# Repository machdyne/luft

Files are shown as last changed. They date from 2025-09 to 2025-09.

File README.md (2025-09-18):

# Luft Air Sensor Controller

Luft is an experimental open-source air sensor controller with sockets for up to four MQ gas sensor modules. In addition to MQ modules, you can also connect a SEN55 module (particulate matter, Volatile Organic Compounds, Nitrogen Oxides, humidity, and temperature) and a I2C oxygen sensor, CO₂ sensor, or other I2C sensors.

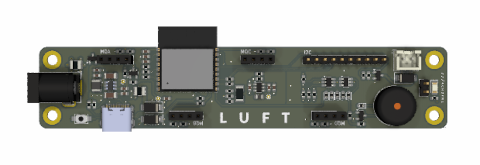
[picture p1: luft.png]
Luft


Luft enables remote monitoring of gasses, air quality and other environmental factors.

The alarm can be triggered by either the MCU or the MQ modules based on their potentiometer setting. The alarm is only activated when JP1 is shunted with a jumper or key switch.

This repo contains schematics, PCB layouts, a DIN-mountable 3D-printable case, and documentation.

Find more information on the [Luft product page](https://machdyne.com/product/luft-air-sensor-controller/).

## Configuration (Tasmota)

### Template

```
{"NAME":"LUFT-ESP32C3","GPIO":[8546,8547,1,8545,8544,1,3872,416,1,1,480,0,0,0,0,0,0,0,1,1,608,640],"FLAG":0,"BASE":1}
```

### Pinout

| GPIO | Function | Description |
| ---- | --- | --- |
| GPIO0 | ADC MQ 3 | MQ3 analog |
| GPIO1 | ADC MQ 4 | MQ4 analog |
| GPIO3 | ADC MQ 2 | MQ2 analog |
| GPIO4 | ADC MQ 1 | MQ1 analog |
| GPIO6 | OUTPUT LOW | MQ power enable |
| GPIO7 | PWM 1 | Fan power control |
| GPIO10 | BUZZER | Buzzer power control |
| GPIO20 | I2C SCL | I2C clock |
| GPIO21 | I2C SDA | I2C data |

### Example Rules

```
# Send MQTT data every 60 seconds
TelePeriod 60

# Socket 1: MQ-135 (GPIO4)
AdcGpio4 135.00, 605.18, -3.937, 15.0

# Socket 2: MQ-2 (GPIO3)
AdcGpio3 2.00, 574.25, -2.22, 15.0

# Socket 3: MQ-6 (GPIO0)
AdcGpio0 6.00, 574.25, -2.22, 15.0

# Socket 4: MQ-9 (GPIO1)
AdcGpio1 9.00, 574.25, -2.22, 15.0
```

### Notes

If you have issues detecting the SEN55 module: https://github.com/arendst/Tasmota/discussions/19027

## Safety

This is an experimental design, use at your own risk. The heating elements in MQ modules can potentially ignite gasses. Luft is intended to be used with the 3D-printable case and an exhaust fan.

## License

The contents of this repo are released under the [Lone Dynamics Open License](LICENSE.md).

Note: You can use these designs for commercial purposes but we ask that instead of producing exact clones, that you either replace our trademarks and logos with your own or add your own next to ours.

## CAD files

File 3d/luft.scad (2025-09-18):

/*
 * Luft Case
 * Copyright (c) 2025 Lone Dynamics Corporation. All rights reserved.
 *
 * required hardware:
 *  - 4 x M3 x 6mm bolts
 *  - 4 x M3 x 25mm bolts
 *  - 8 x M3 nuts
 *
 */

$fn = 100;

board_width = 25;
board_thickness = 1.5;
board_length = 125;
board_height = 1.6;
board_spacing = 2;

case_width = 50;

wall = 2;

top_height = 50;
bottom_height = 6;

translate([wall,wall,0]) mta_board();
translate([28,5-10,45]) mta_fan();

translate([0,0,15])
	mta_case_top();

translate([0,0,-15])
	mta_case_bottom();

translate([45,-4,-20])
    mta_din_clip();
 
translate([45,-25,-20])
	mta_din_endclip();

module mta_board() {
	
	difference() {
		color([0,0.5,0])
			roundedcube(board_width,board_length,board_thickness,3);
		translate([4, 4, -1]) cylinder(d=3.2, h=10);
		translate([4, 121, -1]) cylinder(d=3.2, h=10);
		translate([21, 5, -1]) cylinder(d=3.2, h=10);
		translate([21, 121, -1]) cylinder(d=3.2, h=10);
	}	
	
}

module mta_fan() {
    color([0,0,1]) cube([30,10,30], center=true);
}

module mta_case_top() {

    translate([case_width-8,22.5,40]) cube([10,4,9.5]);

	difference() {
				
		color([0.5,0.5,0.5]) union() {
			roundedcube(case_width+(wall*2),board_length+(wall*2),top_height+1,2.5);
            
            
            
            translate([(case_width+(wall*2))/2+18.5,0,0])
                cylinder(d=17, h=bottom_height);
            rotate([30,0,0]) translate([(case_width+(wall*2))/2+18.5,4,4.25])
                cylinder(d=17, h=bottom_height);
            
            
            
            translate([(case_width+(wall*2))/2+18.5,board_length+(wall*2),0])
                cylinder(d=17, h=bottom_height);
            rotate([-30,0,0]) translate([(case_width+(wall*2))/2+18.5,board_length+(wall*2)-21.5,68.25])
                cylinder(d=17, h=bottom_height);

        }
        
		// cutouts
			
		translate([wall,wall,-1])
			roundedcube(case_width,board_length,50,2.5);

			
		translate([wall, wall, 0]) {

			// vents
            for (i = [5:5:120]) {
                translate([-5,i,20]) cube([20,1,50]);
			}
            for (i = [5:5:120]) {
                translate([35,i,20]) cube([30,1,50]);
			}			

    		// USBC
			translate([-10,board_length-24-(9.5/2),-1]) cube([30,9.5,3.5+1]);

    		// power
			translate([board_width/2-(9.5/2),124,-1]) cube([9.5,5,11.25+1]);

            // key switch
            translate([case_width/2,10,45]) cylinder(d=12, h=15);

            // fan port
            rotate([90,0,0]) translate([case_width/2,30,-1]) cylinder(d=25, h=100);

            // fan bolt holes
            rotate([90,0,0]) translate([case_width/2-12,30-12,-1]) cylinder(d=3.2, h=100);
            rotate([90,0,0]) translate([case_width/2+12,30+12,-1]) cylinder(d=3.2, h=100);
            rotate([90,0,0]) translate([case_width/2-12,30+12,-1]) cylinder(d=3.2, h=100);

            rotate([90,0,0]) translate([case_width/2+10,30-10,-1]) cylinder(d=8, h=100);

            // bolt holes
            translate([case_width/2+18.5, -6, -11]) cylinder(d=3.5, h=25);
            translate([case_width/2+18.5, board_length+6, -11]) cylinder(d=3.5, h=25);
            
			// text
            rotate(270) translate([-(board_length/2),case_width/2-(5/2),top_height+0.5])
                linear_extrude(1)
                    text("L U F T", size=5, halign="center",
                        font="Lato:style=Bold");

		}
		
	}	
}

module mta_case_bottom() {
	
	difference() {
        color([0.5,0.5,0.5]) union() {
            roundedcube(case_width+(wall*2),board_length+(wall*2),bottom_height,2.5);
            translate([(case_width+(wall*2))/2+18.5,0,0])
                cylinder(d=17, h=bottom_height);
            translate([(case_width+(wall*2))/2+18.5,board_length+(wall*2),0])
                cylinder(d=17, h=bottom_height);
        }
        
		// cutouts
		translate([3,9,1.5])
			roundedcube(board_width-3,board_length-15,10,2.5);
				
		translate([9,2.5,1.5])
			roundedcube(board_width-15,board_length-2,10,2.5);

		translate([3,60,1.5])
			roundedcube(case_width-wall,board_length-70,10,2.5);

        // SEN5x compartment
		translate([27+10,wall,1.5])
			cube([14,53,10]);


		translate([wall, wall, 0]) {
			
		// board cutout
		translate([0,0,bottom_height-board_height])
			roundedcube(board_width+0.25,board_length+0.25,board_height+1,2.5);

		translate([wall, wall, 0]) {

    		// USBC
			translate([-1.5,board_length-24-(11/2),1.5]) cube([20,11,3.5+1]);
			
		}

		// bolt holes
		translate([4, 4, -11]) cylinder(d=3.2, h=25);
		translate([4, 121, -11]) cylinder(d=3.2, h=25);
		translate([21, 4, -11]) cylinder(d=3.2, h=25);
		translate([21, 121, -11]) cylinder(d=3.2, h=25);
        
        translate([case_width/2+18.5, -6, -11]) cylinder(d=3.5, h=25);
		translate([case_width/2+18.5, board_length+6, -11]) cylinder(d=3.5, h=25);

		// nut holes
		translate([4, 4, -1]) cylinder(d=7, h=4, $fn=6);
		translate([4, 121, -1]) cylinder(d=7, h=4, $fn=6);
		translate([21, 4, -1]) cylinder(d=7, h=4, $fn=6);
		translate([21, 121, -1]) cylinder(d=7, h=4, $fn=6);

		}
		
	}	
}

// print clips upside down with no supports

module mta_din_clip() {
    
    difference() {
        translate([0,0,-3]) rcube(42,20,6,2.5);
        translate([0,0,-2]) cube([35-3,50,5], center=true);
        translate([0,0,-0.05]) cube([35+1,50,1.1], center=true);
        cylinder(d=3.5, h=50);
        translate([10,0,0]) cylinder(d=3.5, h=50);
        translate([-10,0,0]) cylinder(d=3.5, h=50);
    }
    
}

module mta_din_endclip() {
    
    difference() {
        translate([0,0,-3]) rcube(42,10,6,2.5);
        translate([0,0,-2]) cube([35-3,50,5], center=true);
        translate([0,5,-0.05]) cube([35+1,15,1.1], center=true);
    }
    
}

// https://gist.github.com/tinkerology/ae257c5340a33ee2f149ff3ae97d9826
module roundedcube(xx, yy, height, radius)
{
    translate([0,0,height/2])
    hull()
    {
        translate([radius,radius,0])
        cylinder(height,radius,radius,true);

        translate([xx-radius,radius,0])
        cylinder(height,radius,radius,true);

        translate([xx-radius,yy-radius,0])
        cylinder(height,radius,radius,true);

        translate([radius,yy-radius,0])
        cylinder(height,radius,radius,true);
    }
}

 module rcube(xx, yy, height, radius)
{
    translate([-xx/2,-yy/2,height/2])
    hull()
    {
        translate([radius,radius,0])
        cylinder(height,radius,radius,true);

        translate([xx-radius,radius,0])
        cylinder(height,radius,radius,true);

        translate([xx-radius,yy-radius,0])
        cylinder(height,radius,radius,true);

        translate([radius,yy-radius,0])
        cylinder(height,radius,radius,true);
    }
}

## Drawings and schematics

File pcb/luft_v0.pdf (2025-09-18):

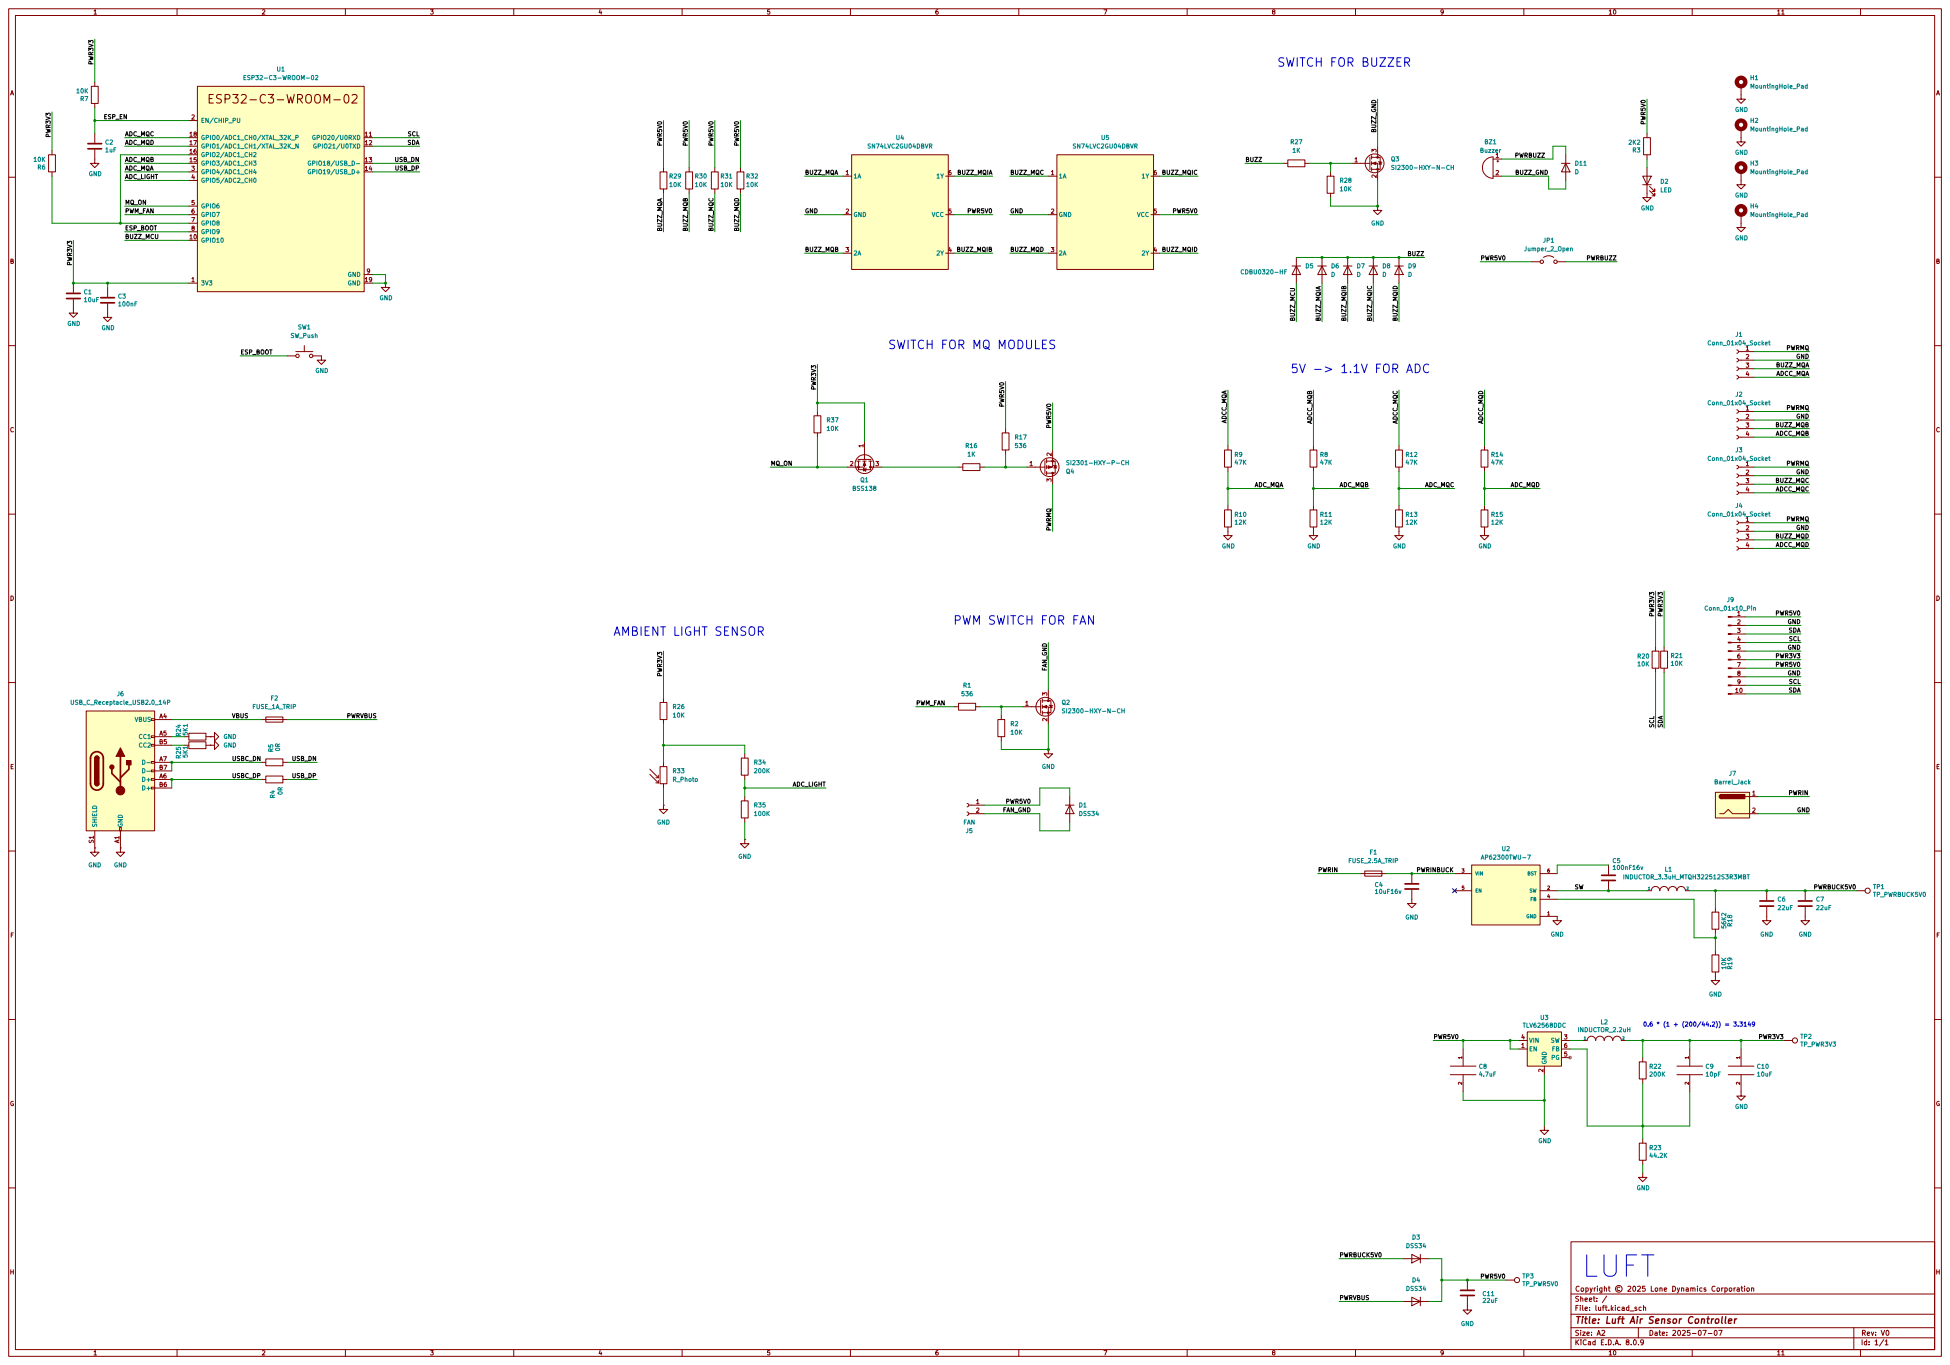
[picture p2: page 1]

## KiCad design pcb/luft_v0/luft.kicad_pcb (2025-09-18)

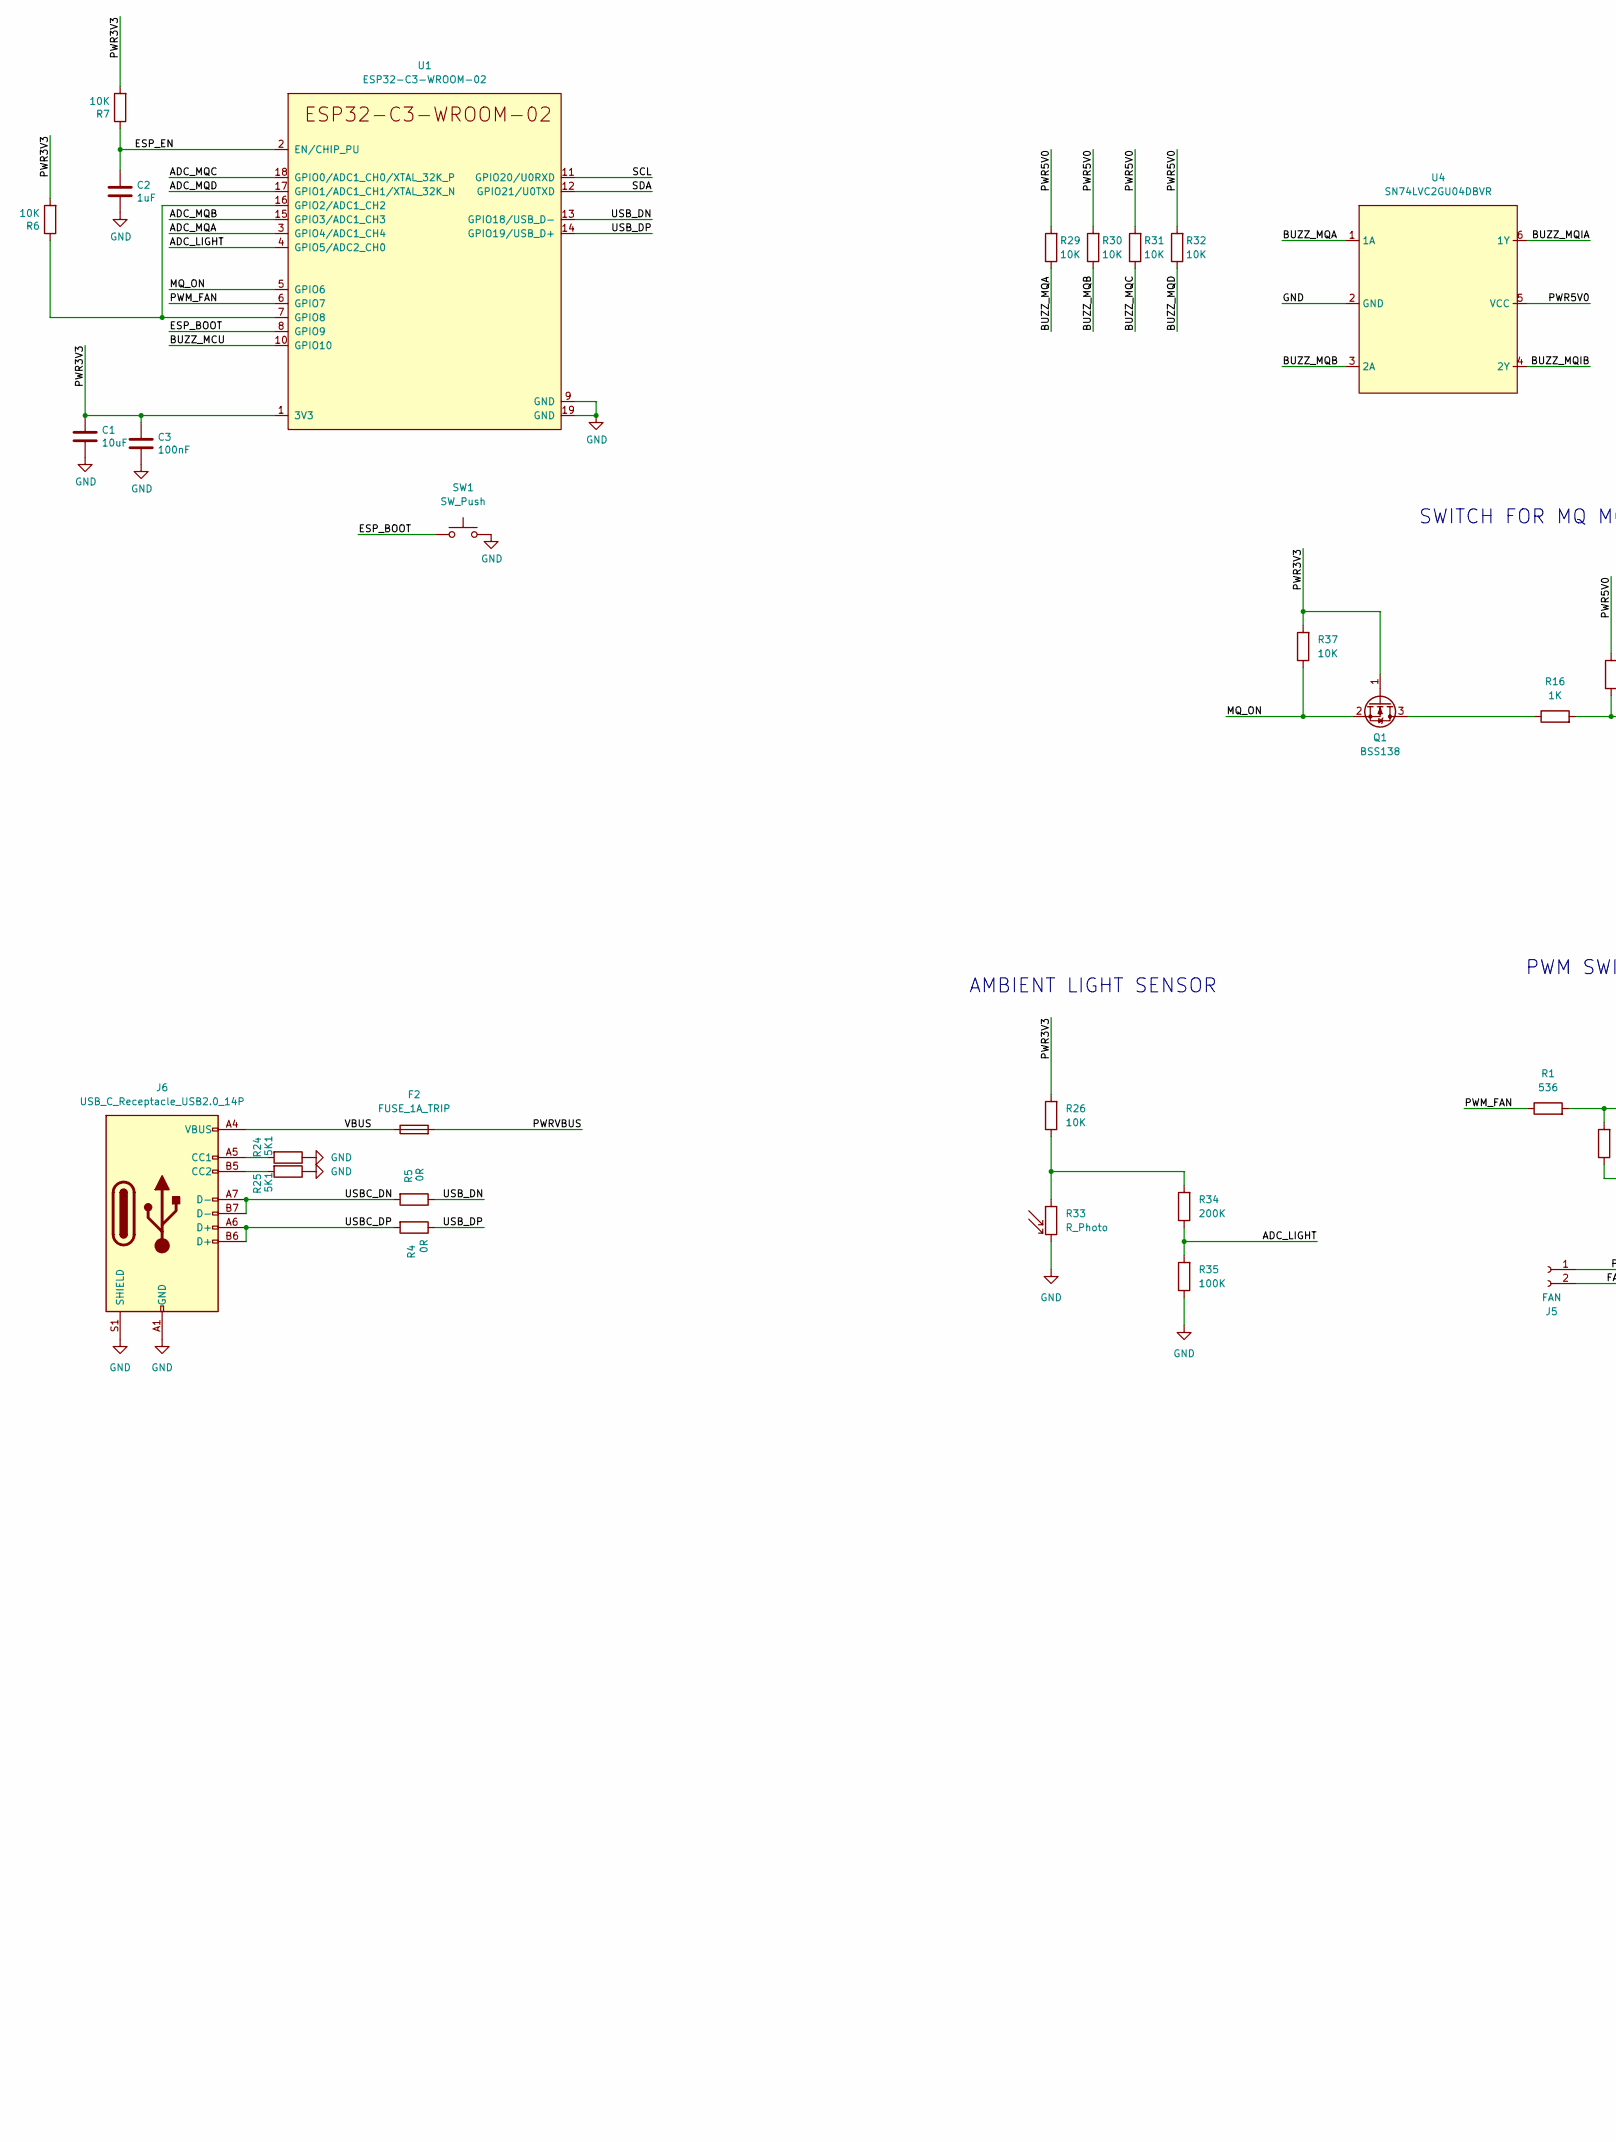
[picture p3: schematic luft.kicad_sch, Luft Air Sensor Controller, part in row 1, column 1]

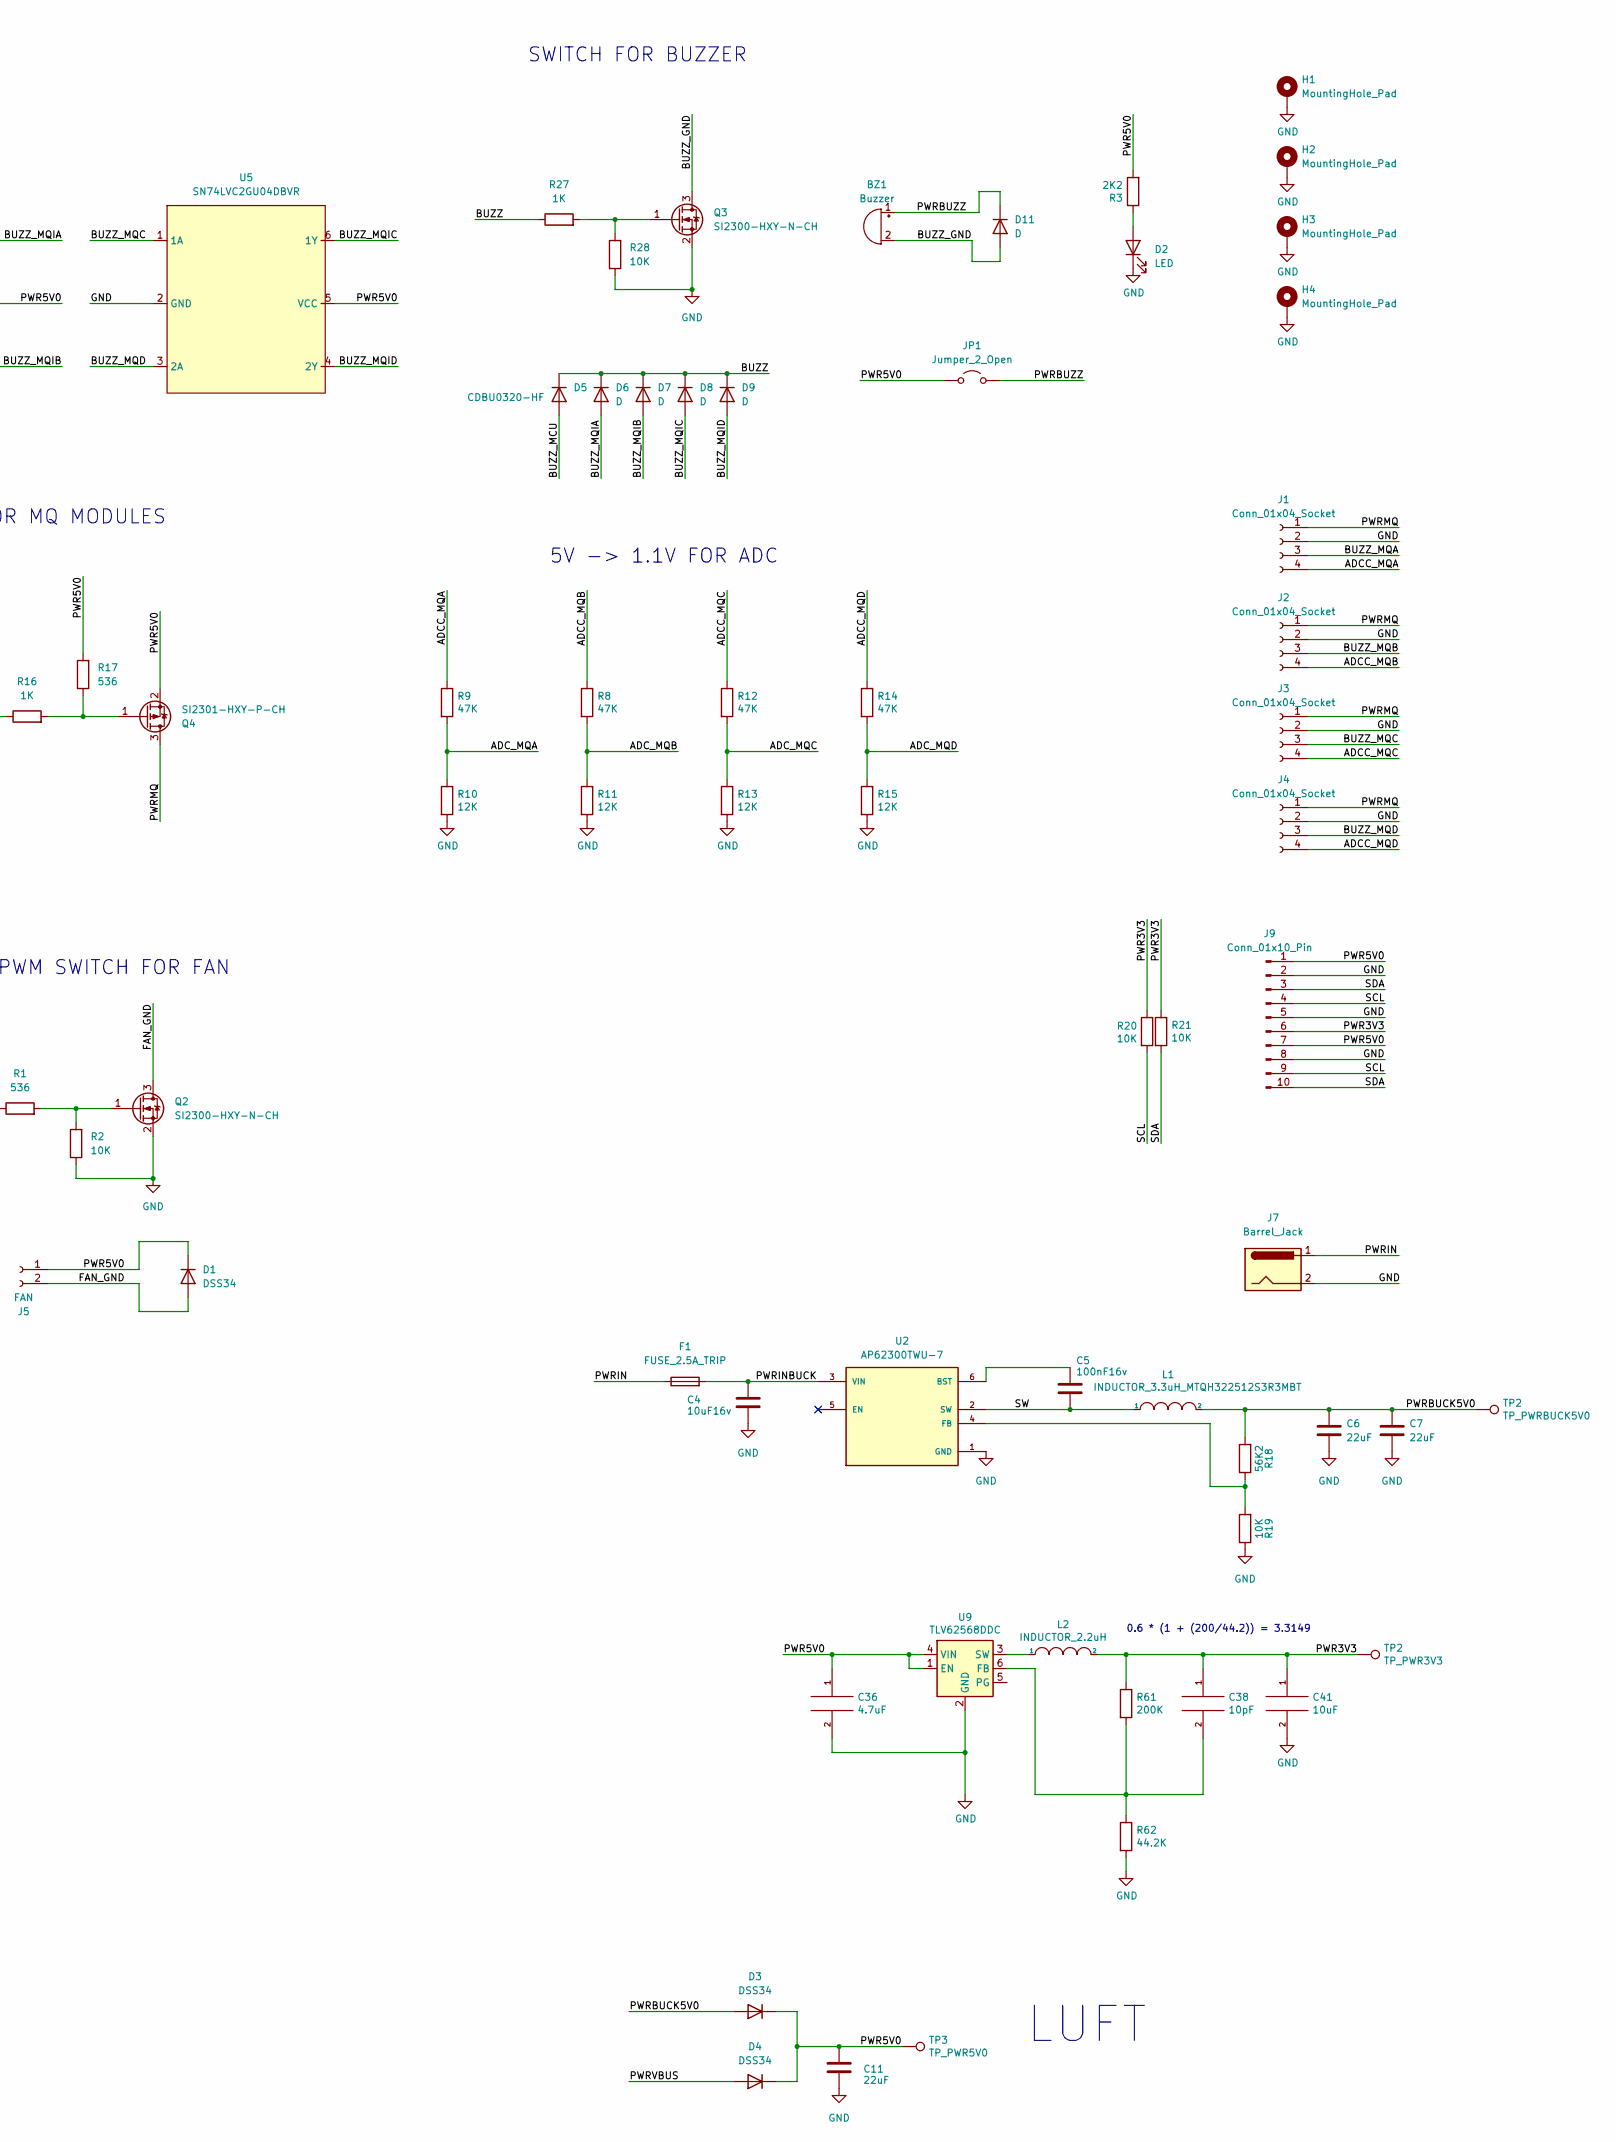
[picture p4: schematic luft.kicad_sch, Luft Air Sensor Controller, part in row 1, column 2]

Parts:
BZ1: Buzzer; Buzzer_12x9.5RM7.6
C1, C41: 10uF; C_0603_1608Metric
C2: 1uF; C_0603_1608Metric
C3: 100nF; C_0603_1608Metric
C4: 10uF16v; C_1206_3216Metric
C5: 100nF16v; C_1206_3216Metric
C6, C7, C11: 22uF; C_0603_1608Metric
C36: 4.7uF; C_0603_1608Metric
C38: 10pF; C_0603_1608Metric
D1, D3, D4: DSS34; D_SMA
D2: LED; LED_1206_3216Metric
D5: CDBU0320-HF; D_0603_1608Metric
D6, D7, D8, D9, D11: D; D_0603_1608Metric
F1: FUSE_2.5A_TRIP; Fuse_1210_3225Metric
F2: FUSE_1A_TRIP; Fuse_1210_3225Metric
H1, H2, H3, H4: MountingHole_Pad; MountingHole_3.2mm_M3_DIN965_Pad
J1, J2, J3, J4: Conn_01x04_Socket; PinSocket_1x04_P2.54mm_Vertical
J5: FAN; JST_XH_B2B-XH-A_1x02_P2.50mm_Vertical
J6: USB_C_Receptacle_USB2.0_14P; USB_C_Receptacle_HRO_TYPE-C-31-M-12-BIG-PADS-PASTE
J7: Barrel_Jack; BarrelJack_GCT_DCJ200-10-A_Horizontal
J9: Conn_01x10_Pin; PinHeader_1x10_P2.54mm_Vertical
JP1: Jumper_2_Open; PinHeader_1x02_P2.54mm_Vertical
L1: INDUCTOR_3.3uH_MTQH322512S3R3MBT; L_1210_3225Metric
L2: INDUCTOR_2.2uH; L_0805_2012Metric
Q1: BSS138; SOT-23
Q2, Q3: SI2300-HXY-N-CH; SOT-23
Q4: SI2301-HXY-P-CH; SOT-23
R1, R17: 536; R_0603_1608Metric
R2, R6, R7, R20, R21, R26, R28, R29, R30, R31, R32, R37: 10K; R_0603_1608Metric
R3: 2K2; R_0603_1608Metric
R4, R5: 0R; R_0603_1608Metric
R8, R9, R12, R14: 47K; R_0603_1608Metric
R10, R11, R13, R15: 12K; R_0603_1608Metric
R16, R27: 1K; R_0603_1608Metric
R18: 56K2; C_0603_1608Metric
R19: 10K; C_0603_1608Metric
R24, R25: 5K1; R_0603_1608Metric
R33: R_Photo; R_PHOTO_3624
R34, R61: 200K; R_0603_1608Metric
R35: 100K; R_0603_1608Metric
R62: 44.2K; R_0603_1608Metric
SW1: SW_Push; Button_2P_3x4mm
TP2: TP_PWRBUCK5V0; TestPoint_THTPad_D1.0mm_Drill0.5mm
TP3: TP_PWR5V0; TestPoint_THTPad_D1.0mm_Drill0.5mm
U1: ESP32-C3-WROOM-02
U2: AP62300TWU-7; SOT95P280X100-6N; PARTREV Rev. 3 - 2
U4, U5: SN74LVC2GU04DBVR; SOT-23-6_Handsoldering
U9: TLV62568DDC; SOT-23-6

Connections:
/ADCC_MQA: J1.4, R9.1
/ADCC_MQB: J2.4, R8.1
/ADCC_MQC: J3.4, R12.1
/ADCC_MQD: J4.4, R14.1
/ADC_LIGHT: R34.1, R35.2, U1.4 (GPIO5/ADC2_CH0)
/ADC_MQA: R9.2, R10.1, U1.3 (GPIO4/ADC1_CH4)
/ADC_MQB: R8.2, R11.1, U1.15 (GPIO3/ADC1_CH3)
/ADC_MQC: R12.2, R13.1, U1.18 (GPIO0/ADC1_CH0/XTAL_32K_P)
/ADC_MQD: R14.2, R15.1, U1.17 (GPIO1/ADC1_CH1/XTAL_32K_N)
/BUZZ: D5.1 (K), D6.1 (K), D7.1 (K), D8.1 (K), D9.1 (K), R27.1
/BUZZ_GND: BZ1.2 (-), D11.2 (A), Q3.3 (D)
/BUZZ_MCU: D5.2 (A), U1.10 (GPIO10)
/BUZZ_MQA: J1.3, R29.1, U4.1 (1A)
/BUZZ_MQB: J2.3, R30.1, U4.3 (2A)
/BUZZ_MQC: J3.3, R31.1, U5.1 (1A)
/BUZZ_MQD: J4.3, R32.1, U5.3 (2A)
/BUZZ_MQIA: D6.2 (A), U4.6 (1Y)
/BUZZ_MQIB: D7.2 (A), U4.4 (2Y)
/BUZZ_MQIC: D8.2 (A), U5.6 (1Y)
/BUZZ_MQID: D9.2 (A), U5.4 (2Y)
/ESP_BOOT: SW1.1, U1.8 (GPIO9)
/ESP_EN: C2.1, R7.1, U1.2 (EN/CHIP_PU)
/FAN_GND: D1.2 (A), J5.2, Q2.3 (D)
/MQ_ON: Q1.2 (S), R37.1, U1.5 (GPIO6)
/PWM_FAN: R1.1, U1.6 (GPIO7)
/PWR5V0: C11.1, D1.1 (K), D3.1 (K), D4.1 (K), J5.1, J9.1, J9.7, JP1.1 (A), Q4.2 (S), R3.2, R17.2, R29.2, R30.2, R31.2, R32.2, TP3.1, U4.5 (VCC), U5.5 (VCC); also elsewhere on the board
/PWRBUZZ: BZ1.1 (+), D11.1 (K), JP1.2 (B)
/PWRIN: F1.1, J7.1
/PWRINBUCK: C4.1, F1.2, U2.3 (VIN)
/PWRMQ: J1.1, J2.1, J3.1, J4.1, Q4.3 (D)
/PWRVBUS: D4.2 (A), F2.2
/SCL: J9.4, J9.9, R20.2, U1.11 (GPIO20/U0RXD)
/SDA: J9.3, J9.10, R21.2, U1.12 (GPIO21/U0TXD)
/SW: C5.2, L1.1, U2.2 (SW)
/USBC_DN: J6.A7 (D-), J6.B7 (D-), R5.2
/USBC_DP: J6.A6 (D+), J6.B6 (D+), R4.2
/USB_DN: R5.1, U1.13 (GPIO18/USB_D-)
/USB_DP: R4.1, U1.14 (GPIO19/USB_D+)
/VBUS: F2.1, J6.A4 (VBUS), J6.A9 (VBUS), J6.B4 (VBUS), J6.B9 (VBUS)
GND: C1.2, C2.2, C3.2, C4.2, C6.2, C7.2, C11.2, D2.1 (K), H1.1, H2.1, H3.1, H4.1, J1.2, J2.2, J3.2, J4.2, J6.A1 (GND), J6.A12 (GND), J6.B1 (GND), J6.B12 (GND), J6.S1 (SHIELD), J7.2, J9.2, J9.5, J9.8, Q2.2 (S), Q3.2 (S), R2.1, R10.2, R11.2, R13.2, R15.2, R19.1, R24.1, R25.1, R28.1, R33.2, R35.1, SW1.2, U1.9 (GND), U1.19 (GND), U2.1 (GND), U4.2 (GND), U5.2 (GND); also elsewhere on the board
unnamed: D2.2 (A), R3.1
unnamed: J6.A5 (CC1), R24.2
unnamed: J6.B5 (CC2), R25.2
unnamed: Q1.3 (D), R16.1
unnamed: Q2.1 (G), R1.2, R2.2
unnamed: Q3.1 (G), R27.2, R28.2
unnamed: Q4.1 (G), R16.2, R17.1
unnamed: R26.1, R33.1, R34.2
unnamed: R6.1, U1.7 (GPIO8), U1.16 (GPIO2/ADC1_CH2)
unnamed: C5.1, U2.6 (BST)
unnamed: R18.1, R19.2, U2.4 (FB)
unnamed 52: L2.1; also elsewhere on the board

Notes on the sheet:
0.6 * (1 + (200/44.2)) = 3.3149
PWM SWITCH FOR FAN
LUFT
AMBIENT LIGHT SENSOR
SWITCH FOR MQ MODULES
SWITCH FOR BUZZER
5V -> 1.1V FOR ADC

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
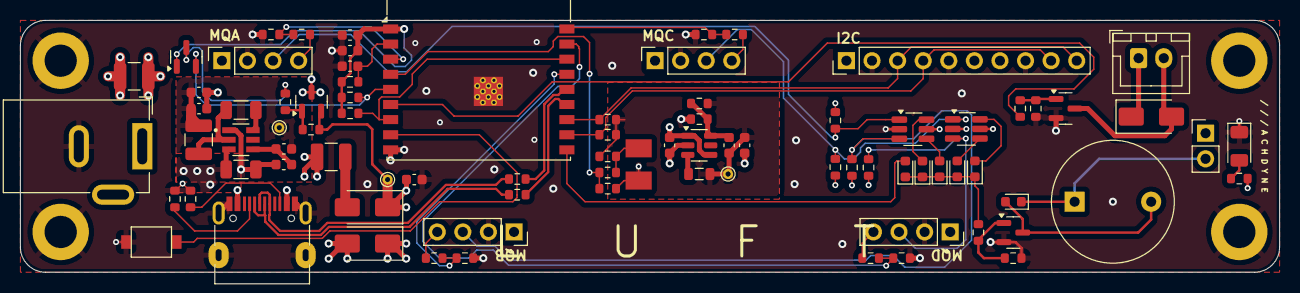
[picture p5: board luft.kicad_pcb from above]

Board: 4 copper layers, 125.0 x 25.0 mm, 88 parts (0 on the bottom side), 55 nets.

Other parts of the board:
C8: 4.7uF; C_0603_1608Metric
C9: 10pF; C_0603_1608Metric
C10: 10uF; C_0603_1608Metric
R22: 200K; R_0603_1608Metric
R23: 44.2K; R_0603_1608Metric
TP1: TP_PWRBUCK5V0; TestPoint_THTPad_D1.0mm_Drill0.5mm
U3: TLV62568DDC; SOT-23-6

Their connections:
/PWR5V0: C8.1, U3.1 (EN), U3.4 (VIN); also elsewhere on the board
GND: C8.2, C10.2, R23.2, U3.2 (GND); also elsewhere on the board
unnamed: C9.2, R22.2, R23.1, U3.6 (FB)
unnamed 52: U3.3 (SW); also elsewhere on the board

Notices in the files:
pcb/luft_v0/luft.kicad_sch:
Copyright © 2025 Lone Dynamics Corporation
